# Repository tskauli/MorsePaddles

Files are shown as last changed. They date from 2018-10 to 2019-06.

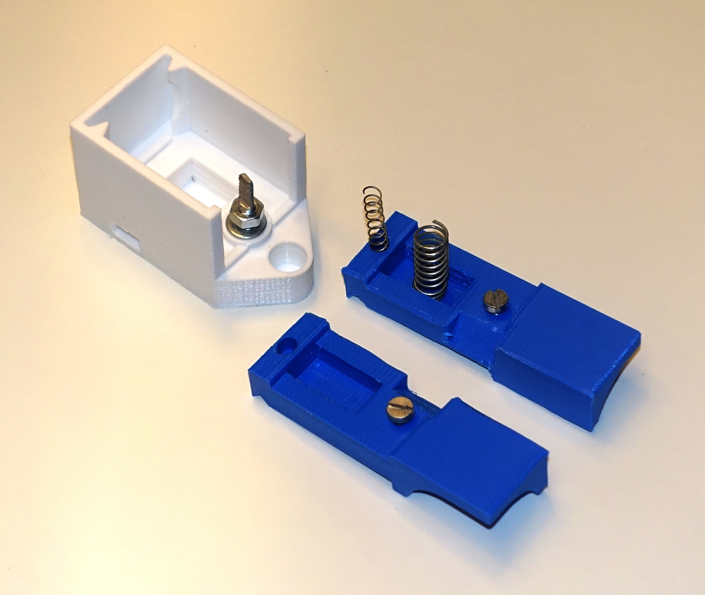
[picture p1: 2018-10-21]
DSC04378_cr_exp.jpg

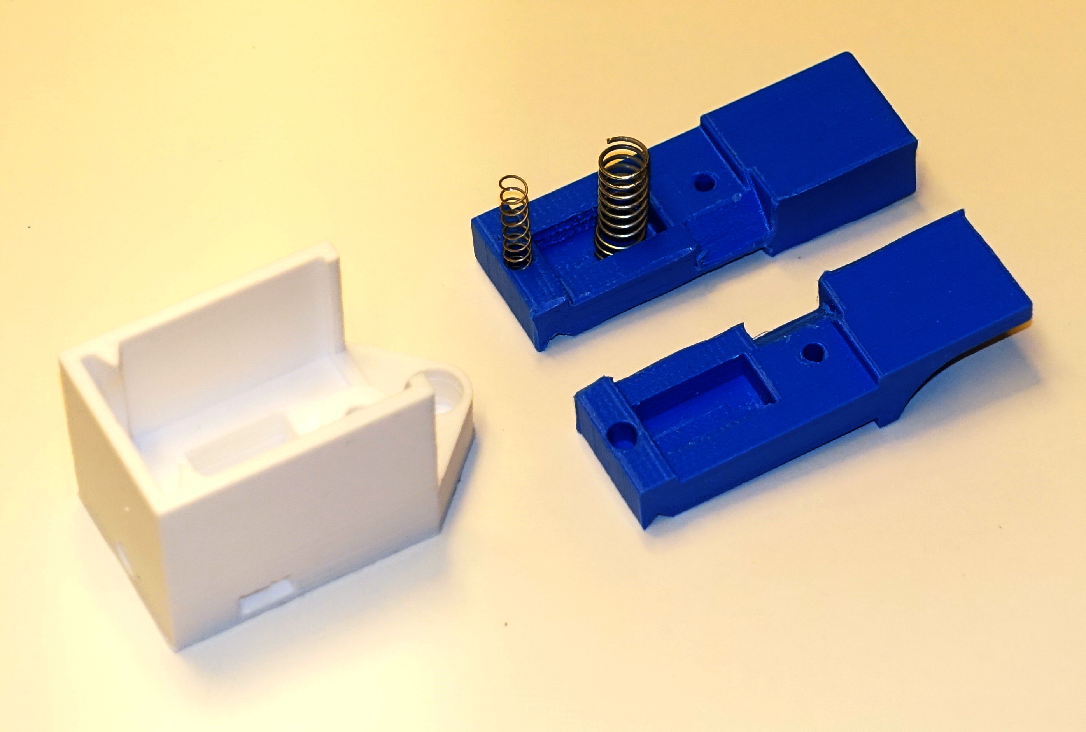
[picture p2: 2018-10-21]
DSC04375_cr_exp.JPG

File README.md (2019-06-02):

# MorsePaddles
This design is for 3D-printed iambic paddles for sending Morse code. The design is simple, but provides precise movement with adjustable force and travel. Design features include a printed rocker hinge, force adjustment by a sliding spring, travel adjustment using a modified screw, ergonomic grip and general simplicity and precision. The design is compact and well suited for portable use.

The version 2 of the paddles is a bit sleeker, and also more robust against pushing the arms out or place, thanks to a base that extends under the full length of the arms. The space inside is a bit more tight, and the central screw has to be shorter. Otherwise the design is essentially the same as the first version. These instructions are not updated with new images of everything, and both designs work just fine. Version 2 is used in the Compact QCX enclosure.

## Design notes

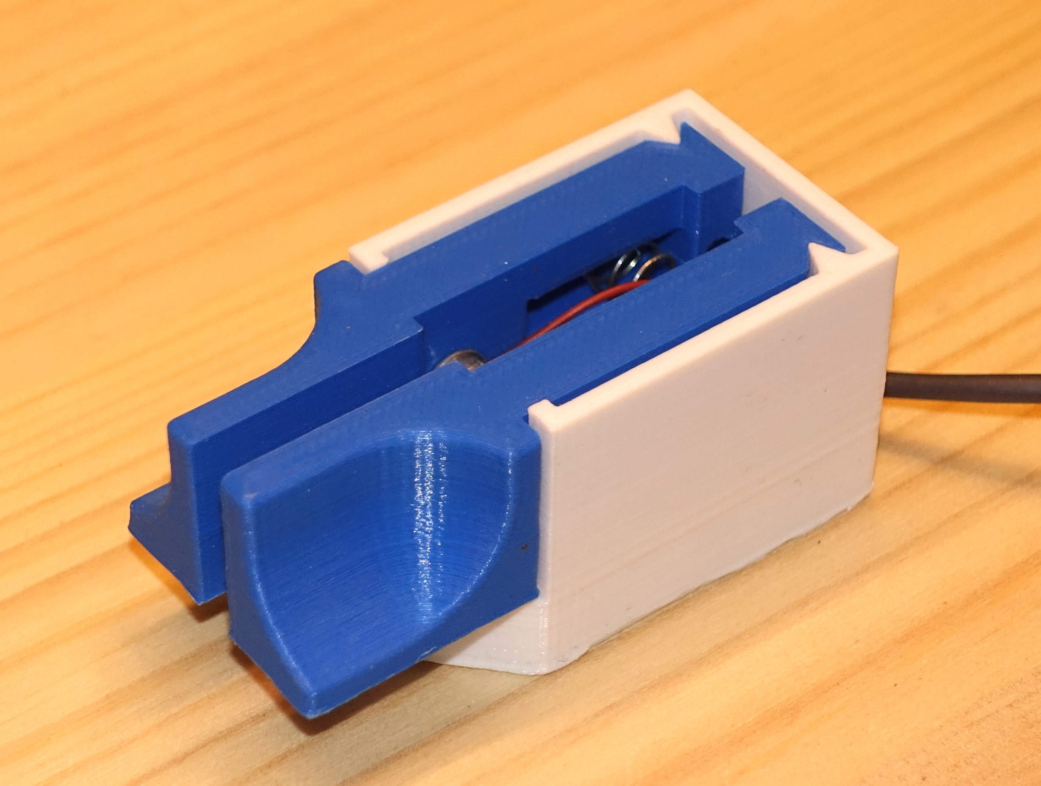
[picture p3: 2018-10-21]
DSC04536_cr_exp.JPG

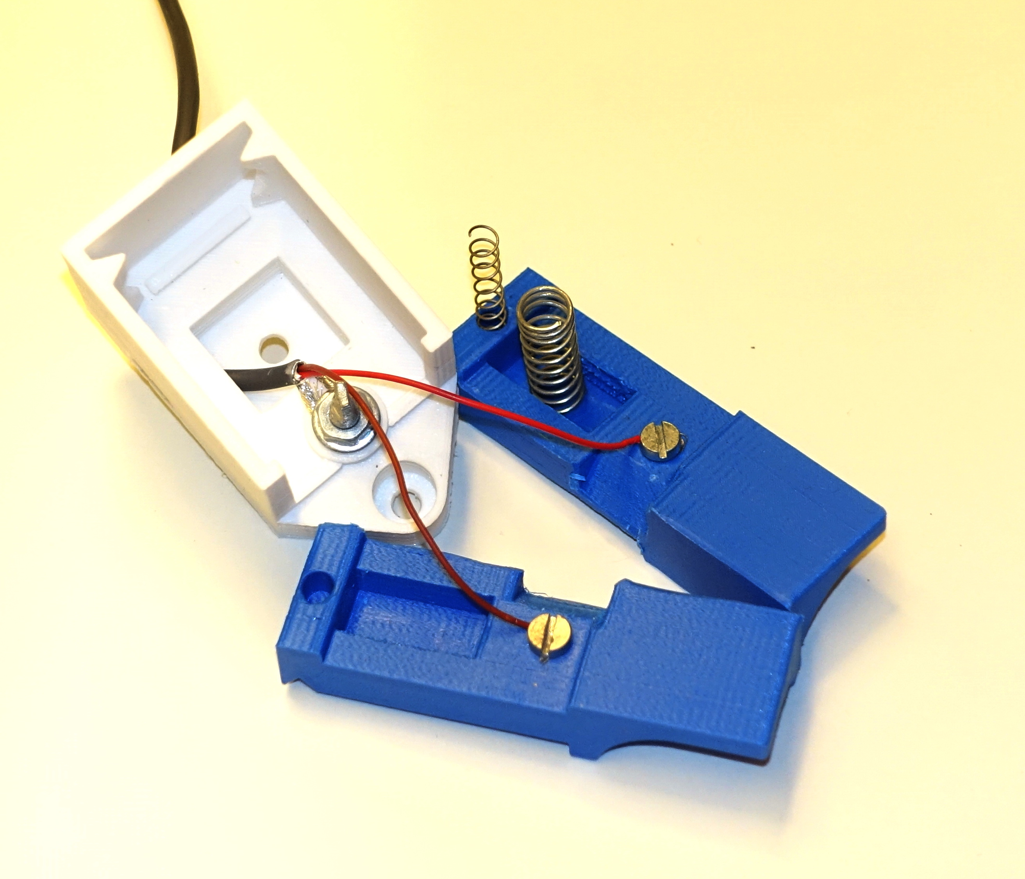
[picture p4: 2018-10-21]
DSC04381_cr_exp.jpg

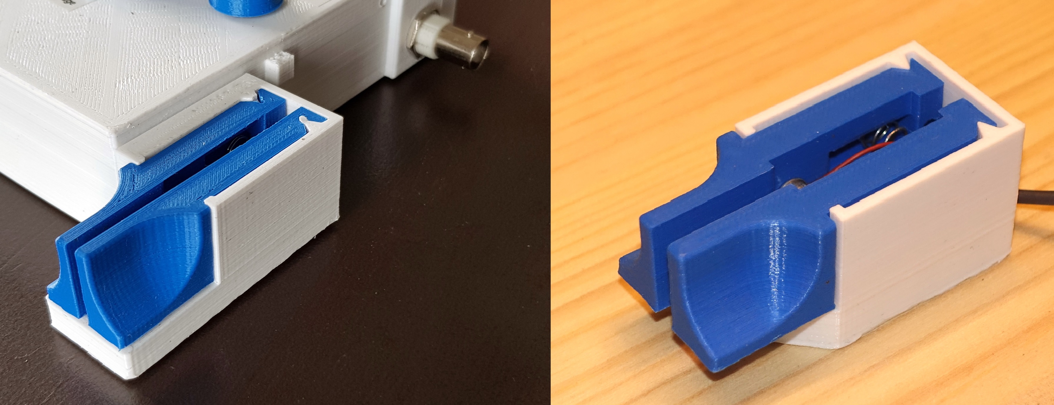
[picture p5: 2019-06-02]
MorsePaddlesV1andV2.jpg

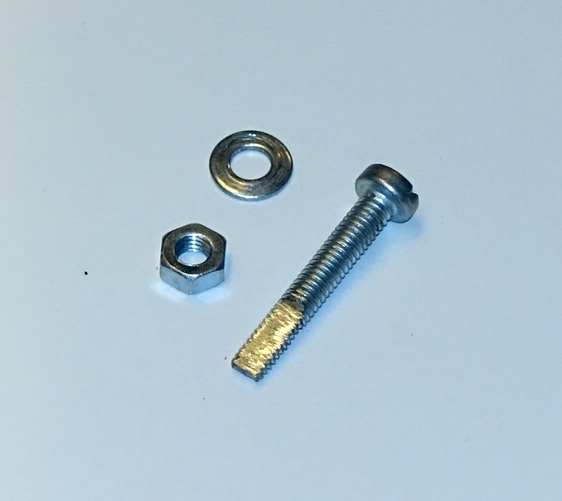
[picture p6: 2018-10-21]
DSC04376_cr_exp.JPG

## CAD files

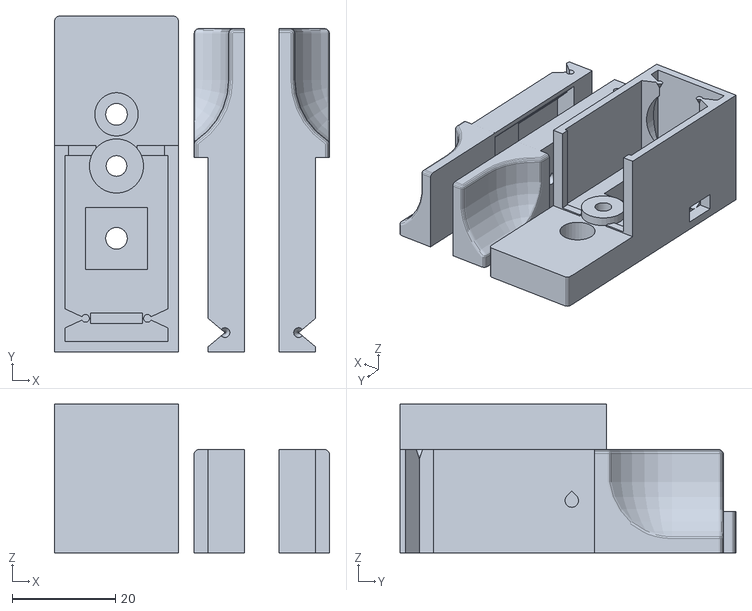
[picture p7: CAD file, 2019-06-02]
MorsePaddlesV2.stl
53.2 x 65.0 x 28.8

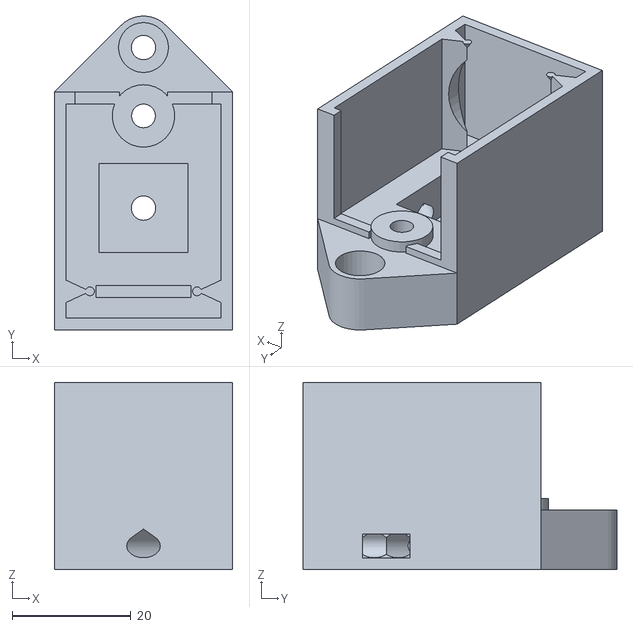
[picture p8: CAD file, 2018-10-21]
MorsePaddlesBase.stl
30.0 x 52.8 x 31.5

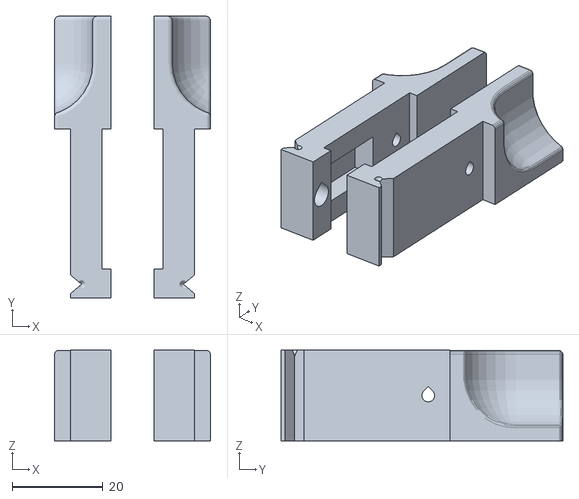
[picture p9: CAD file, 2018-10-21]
MorsePaddlesArms.stl
34.5 x 62.2 x 20.0

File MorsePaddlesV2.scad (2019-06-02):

/*

           >>> COMPACT 3D-PRINTED PADDLES <<<


    Torbjørn Skauli, LA4ZCA (tskauli@gmail.com)

                  v2.0, December 2018


Iambic paddles designed for 3D-printing. The design is simple, but provides precise movement with adjustable force and travel. Design features include a printed rocker hinge, force adjustment by a sliding spring, travel adjustment using a modified screw, ergonomic grip and general simplicity and precision.

Changes in v2.0: The paddles have been made narrower, and the base is thinner. There is an option to remove the bottom mounting holes. The base extends under the paddles to protect them from being pushed upwards. The cable exit is on the side, to fit mounting on the QCX transceiver.

TODO:
-Arms 1-2 mm higher, spring channel longer towards contacts?

Materials:
- 3 printed parts
- 2 screws M3x5mm, cylinder head, with washers for adjustment if needed
- 1 screw M4 x 18-20mm, cylinder head, with lockwasher and nut
- Compression spring, 6-8 mm in diameter
- Compression spring, 4-5 mm in diameter
- Cable with plug as required, up to 3.5 mm diameter
Note: Nickel plated brass screws have been found to give the most reliable contact operation. Dimensions of screws, springs and cable can be changed in the code.

Assembly:

- First, prepare the 3D-printed parts by removing support material in the arm spring well and in the ends of the cable holes. Also remove any protuding edges and bumps by gently filing the surfaces.

- Place the large spring so that it is held between the paddles approximately in the middle of the spring well. Also place the small spring in the holes at the hinge. Temporarily slide the two paddles in place. Check the spring force on the paddles and adjust as desired by either moving the spring along the well or by bending the spring to change its length. Make sure that the small spring keeps the arms in place at the hinges during use.

- Remove 6-8 cm of the outer isolation (if present) of the cable and 1 cm of the inner isolation of each wire. Insert the cable from the back through the diagonal hole, and temporarily pull it out from the side "window". Insert the cable back into the other hole and press the cable bend into the window so that the outer isolation ends in the interior wiring well. This forms a strain relief.

- Prepare a 18-20 mm M4 screw with cylindrical head by grinding the outer 5 mm to flatten two opposing sides. Preferably align the flattened screw end with the slot in the screw head.

- Enter two M3 screws with cylindrical heads into the paddle arms, with the heads facing inwards. Clamp the dot and dash wire ends under these screw heads.

- Enter the M4 screw from the bottom and clamp the ground wire underneath the lockwasher. Tighten the nut quite firmly, while allowing a small amount of adjustment of the screw angle to set the travel distance.

- Place the spring between the paddles and slide them in place. Adjust travel by rotating the M4 screw. If the travel is asymmetric, it may be necessary to correct the difference by placing a washer under the head of one of the M3 screws in the paddle arms.


*/

//*************** Rendering output control
mountholes=true;//Whether to have mounting holes in bottom
cacc=4;         // accuracy of circles, multiplier for $fn. Use cacc=1 for dev/debug, =2-4 for final.
preview=0;      // =0 for print layout,
                // =1 or =2 for 1- or 2-arm assembly preview,
                // =3 for base only
                // =4 for arms print layout,
                // =5 base+attachment preview
                // =6 base modified for attachment to other cabinet
                // =7 attachment for inclusion in other cabinet
                // =8 rotation stopper for inclusion in other cabinet

//**************** main parameters of the design
wxbase=24;      // overall width, sets arm thickness etc.
lybasemin=40;   // length excl. knobs (normally 40, made longer below for QCX)
hzarm=20;       // height of main part of arm
wallt=2;        // wall thikckness
wallmin=2;      // min wall thickness under cable holes

dfinger=30;     // approx diameter of finger for curved knob. Also knob length.
lyknob=25;                             // total length of knob
rround=1;       // radius of rounded edges on knob
txknobmin=2;    // min. thickness of knob

yhinge=6.5;     // y position of hinge relative to back
dxwedge=4;      // height of hinge wedge
ahinginn=50;    // angles for inner and outer part of hinges
ahingout=80;
dstopper=1.5;   // diameter of stopper on top of hinge that keeps arm down

armsep=0.75;     // arm separation from all walls
dyarmrests=2;   // y width of resting and bounding surfaces for arms
minstroke=0.25; // minimum stroke length (at full dia of center screw)

//**************** parameters for non-printed parts
dscrew1=4;      // screw dia, also scales screw head height
dscrew2=3;      // screw dia, also scales screw head height
hscrhrel=2/3;   // screw head height and diam rel to diameter
dscrhrel=7/4;
dzcontact=0.1;    // extra height of all screws
dzsprwell=-1;   // height adjustment of spring well
dcable=4;       // cable diameter
dspring=9.5;    // spring diameter
dhingespring=5; // diameter of spring keeping hinge in place

//*************** Parameters for cabinet attachment, needed to make integrated paddle
daxis=6;        // Diameter of rotation axis tube
lyflange=22;    // Length and height of flange on axis tube
hzflange=13;
atthick=1.5;
rotsnaph=1;     // Height of snaps for paddle attachment rotation
rotstop=7;      // Size of rotation stopper shelf

//**************** parameters for rendering
gap=0.2;        // gap for loose fit
tol=0.025;      // general tolerance
nil=0.001;     // Negligible distance, to correct rendering


lybase=lybasemin; // length of basee ex. knobs
echo("Length of base (mm):",lybase);
hzwall=hzarm+armsep;                        // total height of walls
hzbase=2*wallmin+dcable;                    // height of base under arms
ycontact=lybase-1*dscrew1;                  // position of contact screw

wxarm=wxbase/2-wallt-armsep-hscrhrel*dscrew2-minstroke-dscrew1/2; // arm thickness is the remaining space after removing many contributions to total width
echo("Total height (mm):",hzwall+hzbase);
echo("Total width for QCX (mm):",wxbase+dcable);
echo("Max length of contact screws in arms (mm):",wxarm);
echo("Min length of contact screw in base (mm):",hzbase-hscrhrel*dscrew1+armsep+hzarm/2+dscrew2*dscrhrel/2);
echo("Min length to flatten contact screw in base (mm):",dscrew2*dscrhrel);
wxknob=wxarm+wallt+armsep+hscrhrel*dscrew2;
dxknob=hscrhrel*dscrew2;                    // x offset toward center rel to main arm
hzknob=hzarm;                               // height of knobs
lyarm=lybase-wallt-armsep/2;                // knob spaced armsep/2 from base front

y0sprwell=yhinge-wallt-armsep+dxwedge*tan(ahingout/2);        // starting pos of spring channel
sprfloort=wallt;                            // thickness of floor underneath spring
sprlen=wxbase-2*(wallt+armsep+sprfloort);   // length of spring

dxtip=wxbase/4;                             // diameter of rounded tip with attachment hole
dytip=(wxbase-dxtip)/2;                     // length of tip ex rouned part
rtip=dxtip*sqrt(2)/2;                       // radius of tip
ycentip=lybase+dytip-rtip/sqrt(2);          // center of rounded tip
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

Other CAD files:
MorsePaddles.scad

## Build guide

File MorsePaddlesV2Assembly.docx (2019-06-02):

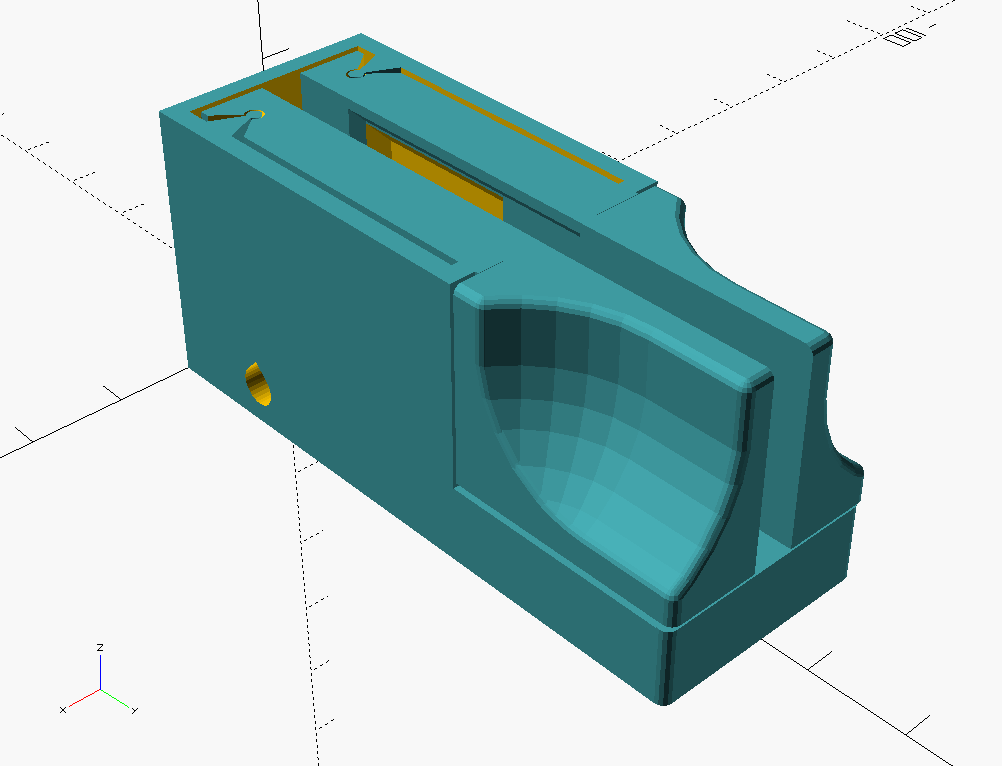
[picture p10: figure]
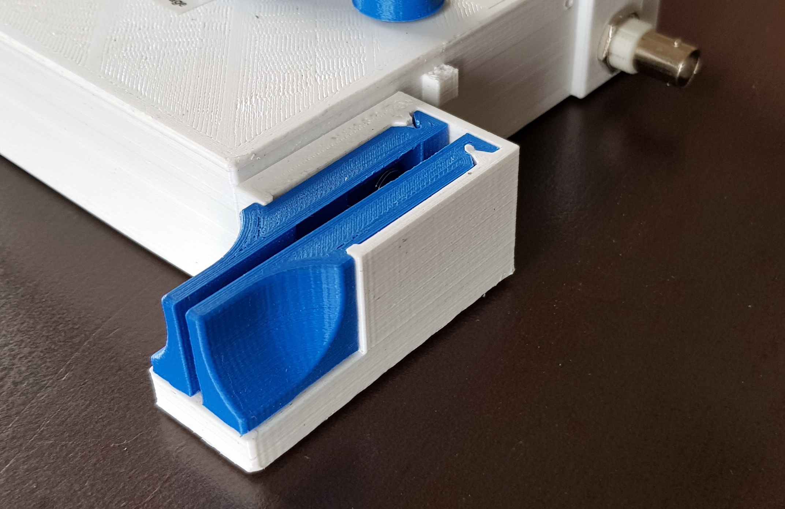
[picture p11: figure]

# Morse Paddles LA4ZCA, v2

## Description

This design is for 3D-printed iambic paddles for sending Morse code. The design is simple, but provides precise movement with adjustable force and travel. Design features include a printed rocker hinge, force adjustment by a sliding spring, travel adjustment using a modified screw, ergonomic grip and general simplicity and precision. The design is compact and well suited for portable use.

The version 2 of the paddles is a bit sleeker, and also more robust against pushing the arms out or place, thanks to a base that extends under the full length of the arms. The space inside is a bit more tight, and the central screw has to be shorter. Otherwise the design is essentially the same as the first version. These instructions are not updated with new images of everything, and both designs work just fine. Version 2 is used in the Compact QCX enclosure (https://github.com/tskauli/QCX_enclosure_LA4ZCA).

Spring force is adjusted by moving the spring closer or further away from the hinge. The center screw forms the common contact and is flattened to a blade shape at the contact points. By rotating the center screw, accessible from the bottom, the length of travel is adjusted by changing the angle of the blade. The paddles need attachment to a steady surface for good ergonomy. Holes for attachment screws are provided. Alternatively, an adhesive can be used: "Blu-tack" putty works well, and is removable.

## Materials:

- 3 printed parts
- 2 screws M3x5mm, cylinder head, with washers for adjustment if needed
- 1 screw M4x18-20mm, cylinder head, with washer and nut
- Compression spring, 6-8 mm in diameter
- Compression spring, 4-5 mm in diameter
- Cable with plug as required, up to 3.5 mm diameter

Note: Nickel plated brass screws have been found to give the most reliable contact operation. Dimensions of screws, springs and cable can be changed in the code.

## Assembly

First, prepare the 3D-printed parts by removing support material in the arm spring well and in the ends of the cable holes. Also remove any protuding edges and bumps by gently filing the surfaces.

Place the large spring so that it is held between the paddles approximately in the middle of the spring well. Also place the small spring in the holes at the hinge. Temporarily slide the two paddles in place. Check the spring force on the paddles and adjust as desired by either moving the spring along the well or by bending the spring to change its length. Make sure that the small spring keeps the arms in place at the hinges during use.


Remove 6-8 cm of the outer isolation (if present) of the cable and 1 cm of the inner isolation of each wire. Insert the cable from the back through the diagonal hole, and temporarily pull it out from the side "window". Insert the cable back into the other hole and press the cable bend into the window so that the outer isolation ends in the interior wiring well. This forms a strain relief.

Prepare a 25 mm M4 screw with cylindrical head by grinding the outer 10 mm to flatten two opposing sides. Preferably align the flattened screw end with the slot in the screw head.

Enter two M3 screws with cylindrical heads into the paddle arms. The screws should be able to self-thread into the holes, but depending on the printer it may be necessary to adjust the hole diameter. Clamp the dot and dash wire ends under these screw heads.

Enter the M4 screw from the bottom and clamp the ground wire underneath the washer. Tighten the screw firmly, while allowing a small amount of adjustment of the screw angle to set the travel distance.

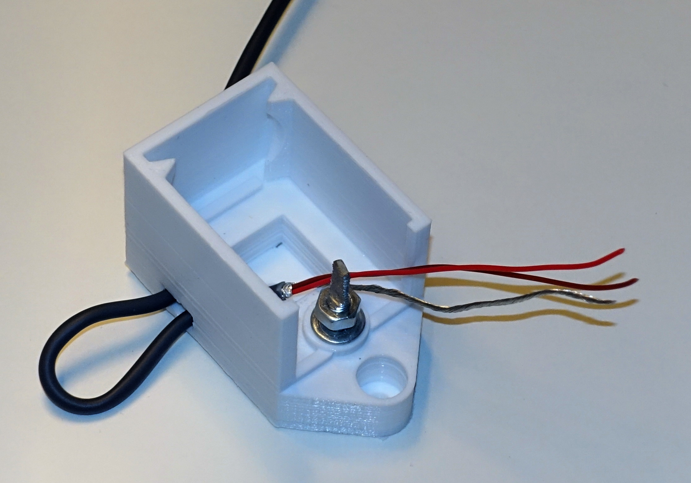
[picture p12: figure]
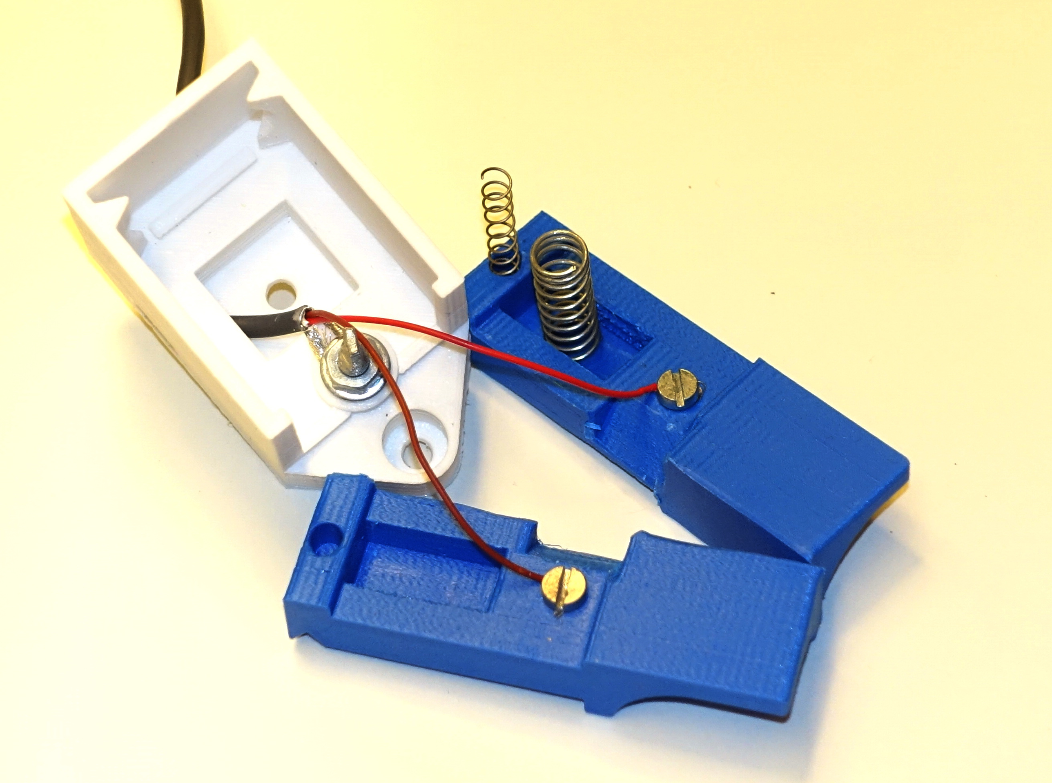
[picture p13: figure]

Place the springs between the paddles and slide the arms in place. Adjust travel by rotating the M4 screw. If the travel is asymmetric, it may be necessary to correct the difference by placing a washer under the head of one of the M3 screws in the paddle arms.

73 de Torbjorn, LA4ZCA (tskauli@gmail.com)

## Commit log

2018-10-22 Fix rendering in Thingiverse
    [MorsePaddles.scad]
2019-06-02 Version 2 added
    [MorsePaddlesV2.scad, MorsePaddlesV2.stl]
